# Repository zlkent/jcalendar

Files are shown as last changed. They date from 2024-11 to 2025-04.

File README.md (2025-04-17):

# J-Calendar
墨水屏日历，采用三色4.2寸墨水屏，展示基本月历信息，支持农历、公共假期、倒计日、天气（实时天气、每日天气）展示。<br>
项目以低难度、低成本的方式，方便爱好者实现属于自己的低功耗月历。<br>
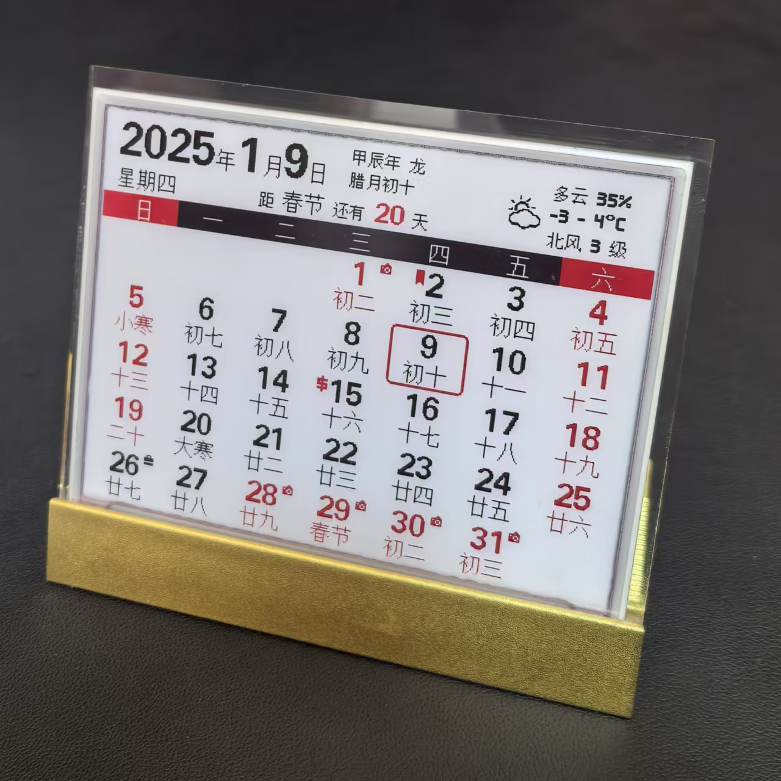
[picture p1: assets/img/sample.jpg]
<br>
Bilibili连接：https://www.bilibili.com/video/BV1wHDhYoE3G/<br>
注：固件仅供个人下载免费使用，禁止商用。

## Prepare & Meterial
1. esp32开发板(建议lolin32 lite,其他esp32开发板亦可)<br>
2. 4.2寸三色墨水屏(400*300)。
3. 通用墨水屏驱动板。
4. 锂电池,需要做ph2.0接头。(建议603048, 900mah)
5. 金属底座亚克力台卡,95*80mm。
6. 轻触开关,(12\*12\*7.3,带键帽)
7. 工具:电烙铁、电线若干。

## Manufacture Guide:
1. 开发板接线<br>
    * 墨水屏驱动板
        * Busy->4
        * RST->16
        * DC->17
        * CS->5
        * SCK->18
        * SDA->23
        * GND->GND
        * VCC->3V
    * 其他
        * 按钮->(PIN_14, GND)
        * LED->22(板载)
2. 三色墨水屏排线插入时注意针脚方向,屏幕排线和驱动板排线1号针脚均是悬空,注意对齐。
3. 电池接口需要是ph2.0,且注意正负极(开发板上有标注),如果电池的正负极反了,可以用镊子调整电池插头。
4. 烧录固件<br>
    使用ESP32的烧录工具flash_download_tool烧录固件. [Flash Download Tools](https://www.espressif.com/en/support/download/other-tools?keys=flash+download+tools)
    1. 选择烧录的文件和烧录地址（bootloader.bin与partitions.bin烧录过一次后，就不需要重复烧录了）
    2. 选择Flash的配置信息
    3. 选择连接的串口以及波特率（波特率可以根据实际情况调整）
    4. 擦除Flash。
    5. 开始烧录。<br>
    <span style="color:red">注：文件前面一定要打勾，否则不会刷进flash的！！！</span><br>
    （参考下图）<br>
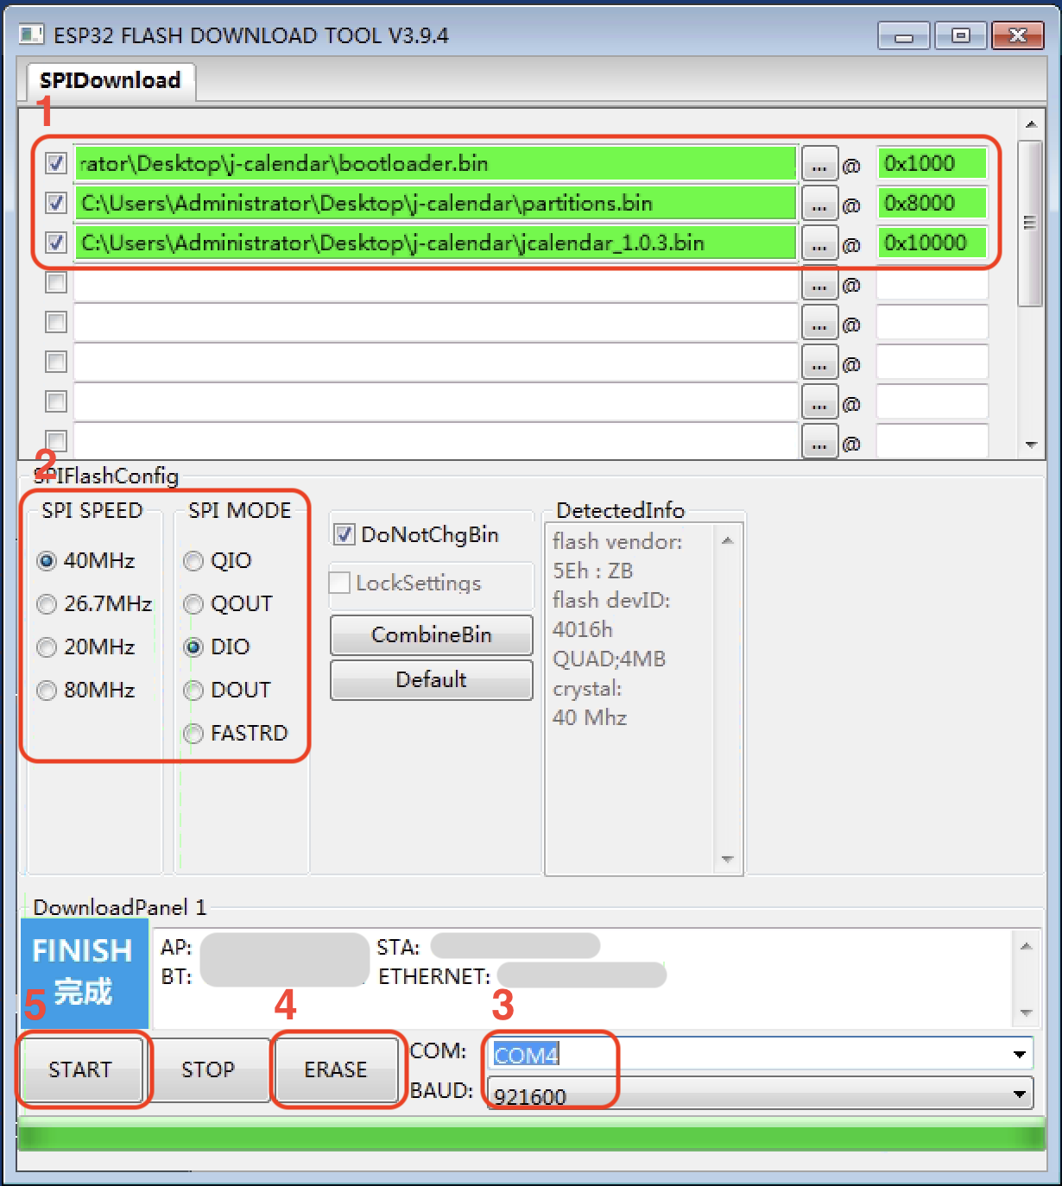
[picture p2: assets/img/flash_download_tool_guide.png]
    
5. 安装盒，3D打印，用PLA或ABS均可。[E-ink box2 v22.3mf](./assets/file/E-ink%20box2%20v22.3mf)

## Button Operation Guide:
1. **单点**  
    如果处在休眠中,唤醒系统,并强制刷新月历。
    如果处在运行中,强制刷新日历。
    如果处在配置中,不做任何处理。
2. **双击**  
    系统正常运行中,双击进入系统配置。(并强制停止WIFI相关操作,如获取天气。)
    系统配置状态中,双击重启系统。
3. **长按**  
    系统运行中,长按清除配置信息(WIFI密钥除外)和缓存,并重启。

## LED Indicator: 
(板载LED,PIN-22)
1. 快闪: LED每秒闪约两次，系统启动中(正在连接WIFI)
2. 常亮: WIFI连接完成。
3. 慢闪: LED每两秒闪一次，WIFI连接失败（10秒钟后休眠）。
4. 三短闪一长灭: 系统配置中。（3分钟后超时休眠）
5. 熄灭: 系统休眠。

## Web Config Guide:
通过在开机状态下(LED常亮)双击,即可进入配置状态,这时系统会生成一个名为J-Calendar的ap,默认密码为:password。(默认超时时间为180秒)
连接上ap后会直接弹出配置页面。(或者直接通过浏览器输入地址 http://192.168.4.1进入)。
配置页面:
1. Config Wifi. Wifi配置  
    进入配置wifi页面,选择搜索到的ap,并输入密码,并保存。
2. Setup. 系统配置  
    * 周首日:
        * 0: 周日(默认); 1: 周一;
    * 和风天气:
        * 输入和风天气的API Key和城市id(城市对应的id请在和风天气的官网查找。)系统会每2小时刷新当前天气,如果Key置空,天气将不会被刷新。<br>
        * 天气类型：0:每日天气（默认，每天凌晨刷新一次）; 1: 实时天气(每两个小时刷新一次天气)<br>
        * 位置：城市id或者经纬度 例1: 101010100 例2: 116.41,39.92<br>
        [城市id列表](./assets/file/China-City-List-latest.csv) <br>
    * 倒数日:<br>输入倒数日名称和日期,名称不能超过4个中文字符,时间以yyyyMMdd的格式填入。配置正确的话,日历每天会显示倒数“距****还有**天”。如果倒数日名称为空,系统将不显示倒数日信息。
    * 日期Tag:<br>
        1. 输入格式，yyyyMMddx，yyyy为年，每年显示设为0000，MM为月份，每月显示设为00，dd为日期，x为tag的图标（a:书签；b：金钱；c：笑脸；d：警告）。例如：00000015b，每年每月15日旁边显示$符号；00000312a，每年3月12日，显示书签符号。
        2. 最多可以设置三个tag，中间以分号隔开。例如：00000015b;00000312a
    * 保存配置后，系统自动重启。
3. Update. OTA升级  
    此项需要在浏览器内完成,通过ip地址访问配置页面,然后进入Update,选择固件文件后上传,等待。刷新完成后,页面会有成功提示。
4. Restart. 重启  
    在所有配置完后,需要重启生效。(也可以在配置状态下,双击按钮重启)
5. Info. 系统信息
    可以监控系统的硬件情况,也可以在里面清除配置的Wifi密钥。
6. Exit. 退出  
    退出配置状态。

## Q & A
1. Q: 刷完机后，如何配置？启动流程是如何的？<br>
A: 需要在系统运行状态下（状态灯常亮或慢闪时）双击按键，即可进入配置状态。LED灯变成三短闪一长灭时说明进入配置状态了。
2. Q: 刷完机后，没有反应该如何处理？<br>
A: 观察22针脚的LED是否点亮，有闪烁说明固件已经刷入，如果没有闪烁可以尝试点击重置按钮重启，或者拔掉电源线和usb线，重插来重启。此外，还可使用串口工具通过usb的com口获取启动日志来进一步确认故障原因。
3. Q: 可以支持哪种屏？<br>
A: 仅4.2寸三色屏(目前仅支持黑白红,将来支持黑白黄)。
4. Q: 我使用的屏应该烧录哪个固件？<br>
A: 从经验上预估，SES的拆机屏选z21，比较新一些的选z98，如果是非常老的屏，选z15。实在不行的话，三个固件都刷一遍试试。<br>
明确的丝印对应如下：<br>
    |丝印|固件|
    |-----|-----|
    |E042A43-A0|z98|
    |P420010|z98|
    |A13600**|z21|
5. Q: 使用flash download tool刷新固件时，报错，连接串口失败。<br>
A: 1. 检查USB线连接是否正常。 <br>2. app的串口下拉框里是否检测到COM口。 <br>3. 把其他串口工具关闭，防止占用COM口。
6. Q: 刷新固件的过程中提示报错。<br>
A: 1. 换根质量较好的或短一些的USB线，或换个USB口插入。 <br>2. 可以将刷新的波特率降低一点，如选择速率低一点的115200。
7. Q: 刷新固件后，需要重新配置吗？
A: 仅刷新app固件后，配置是保留的，所以，无需重新配置。如果刷新了分区表partition.bin，会将esp的nvs区刷新，这时候需要重新配置。
8. Q: 填入和风天气的API Key和位置ID后，没有成功获取天气信息。
A: 2025年3月1日后注册的和风天气账户有API Host限制，请下载1.0.25以后版本，在配置时配置API Host信息。

## Releases
### 1.0.25 (未测试)
* Fix: 和风天气api变更，需要输入API Host（在配置页面增加配置项）
### 1.0.24
* Refine: 配置页面location约束改为64长度，允许输入经纬度设置天气位置（e.g. 116.41,39.92）
### 1.0.23
* Refine: 修改和风天气请求url。
* Fix: bug(获取holiday返回码)。
### 1.0.22
* 项目开源：此项目使用GNU General Public License v3.0许可证授权。详情请参阅LICENSE文件。
* Refine：农历计算功能移出。（农历功能作为独立库，以MIT协议开源）
### 1.0.21
* Fix: bug (wrong background color of calender header).
### 1.0.20
* Fix: bugs.
### 1.0.19
* New: 假日信息通过网络API获取。
* Refine: 由于esp32内置时钟的误差，会有可能唤醒的时间不准确，同时，由于处于午夜0点左右，导致提前刷新或在刷新期间切换日期，导致日期显示不准确。处理方式：计时器唤醒的情况下，23:50以后不刷新直接休眠，等待至0点以后唤醒刷新。
### 1.0.18
* Fix: 修正Wifi连接失败后，同步时间导致系统时间错误。
### 1.0.17
* Refine: 如果wifi连接失败，等待10s再休眠，并增加LED慢闪作为指示。（在这时间段内供用户进行双击打开配置状态）
* Fix: 修正倒数日名称显示不足的问题。
### 1.0.16
* New Feature: UI调整，新增今日农历日期的展现。
### 1.0.15
* Fix: 编译异常。
### 1.0.14
* Fix: bug(假日颜色不正确), 增加显示假日和调休icon(日历右上角)。
### 1.0.13
* Fix: bugs.
### 1.0.12
* 新功能：增加设置每周首日，默认首日为周日。
### 1.0.11
* 优化：补充部分公历&农历节日
### 1.0.10
* 新功能：增加日期Tag（通过配置页面进行配置）
### 1.0.9
* 优化：
    1. 统一每日天气与实时天气的布局。
    2. 增加时间容错性，当同步网络时间失败的时候，使用天气api的更新时间。
* 新功能：增加节日显示（元旦、劳动节、国庆节）
### 1.0.8
* 优化显示：加粗当前日期框；不再使用局刷，全部改为全屏刷新（提高显示的清晰度，兼容不支持局部刷新的三色屏）。
* 预置2025年公休假信息。
### 1.0.7
* 增加24节气显示。修复部分bug。
### 1.0.6
* 增加天气模式--*每日天气*（默认配置），每天刷新一次。（增加月历待机时长。部分不支持局刷的屏可以选择这个模式。）
### 1.0.5 
* 增加强制刷新处理(单击按钮)。
* 修复日历功能、修复日历字典数据
* 修复部分bug。
### 1.0.4<br>
* 增加倒计日功能
* 修复部分bug。
### 1.0.3
* 基本功能
* 功耗优化等

## License
此项目使用GNU General Public License v3.0许可证授权。详情请参阅LICENSE文件。

### ★★★固件还不错，支持一下★★★
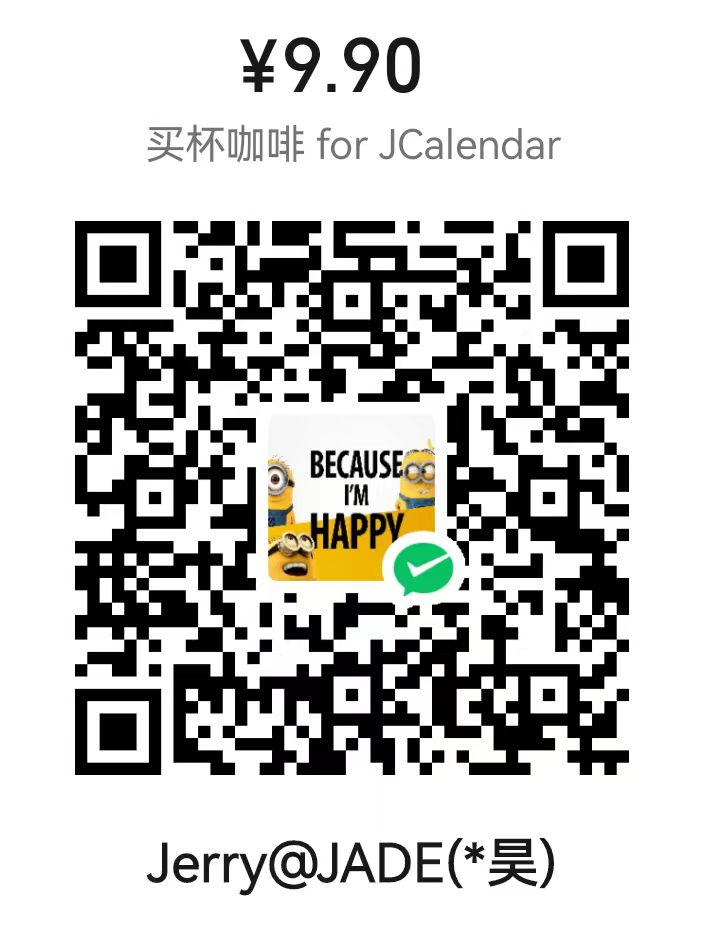
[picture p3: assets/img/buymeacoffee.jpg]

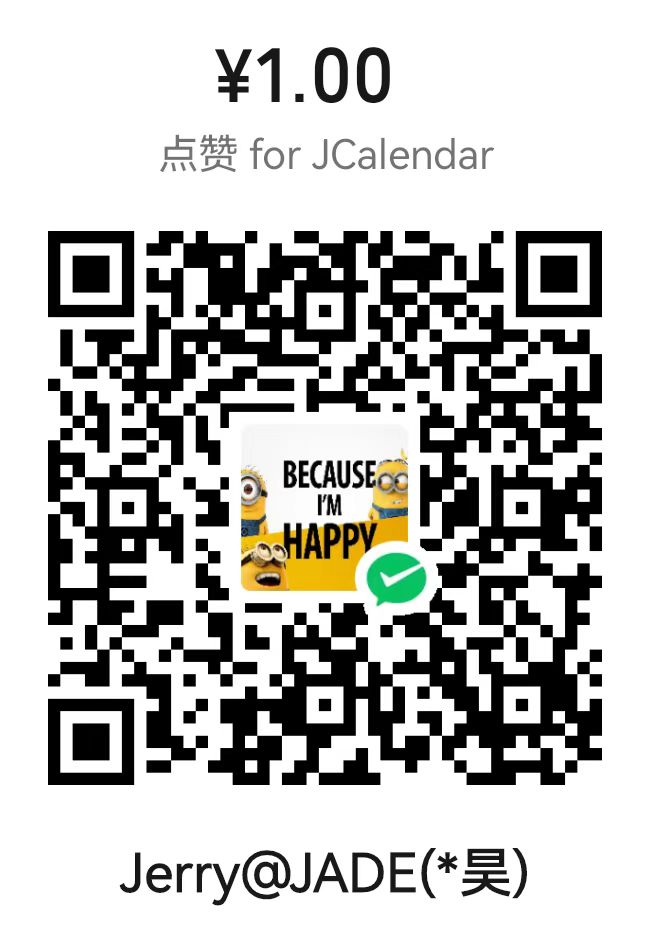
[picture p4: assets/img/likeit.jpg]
<br>

## Reference:
1. \<WEMOS LOLIN32簡介\> https://swf.com.tw/?p=1331&cpage=1
2. \<GxEPD2\> https://github.com/ZinggJM/GxEPD2
3. \<U8g2_for_Adafruit_GFX\> https://github.com/olikraus/U8g2_for_Adafruit_GFX
4. \<和风天气\> https://dev.qweather.com/docs/api/weather/weather-now/
<br>
 Copyright © 2023-2025. All Rights Reserved.

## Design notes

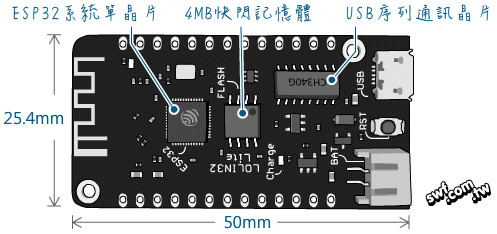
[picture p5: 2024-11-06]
assets/img/LOLIN32_Lite.png

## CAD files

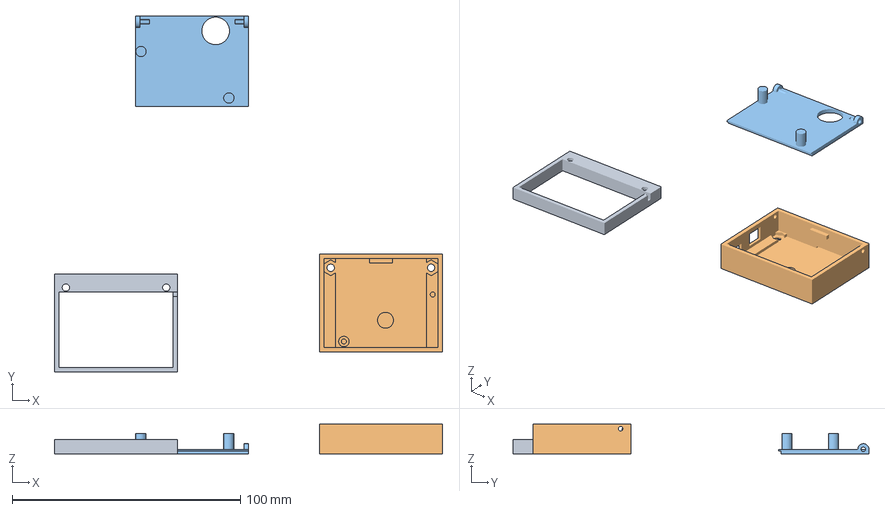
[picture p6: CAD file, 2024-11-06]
assets/file/E-ink box2 v22.3mf
170.1 x 156.0 x 13.0 mm
零部件3
零部件1
实体1.stl

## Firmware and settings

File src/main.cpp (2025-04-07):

#include <Arduino.h>
#include <ArduinoJson.h>

#include <WiFiManager.h>

#include "OneButton.h"

#include "led.h"
#include "_sntp.h"
#include "weather.h"
#include "screen_ink.h"
#include "_preference.h"

#include "version.h"

#define PIN_BUTTON GPIO_NUM_14 // 注意：由于此按键负责唤醒，因此需要选择支持RTC唤醒的PIN脚。
OneButton button(PIN_BUTTON, true);

void IRAM_ATTR checkTicks() {
    button.tick();
}

WiFiManager wm;
WiFiManagerParameter para_qweather_host("qweather_host", "和风天气Host", "", 64); //     和风天气key
WiFiManagerParameter para_qweather_key("qweather_key", "和风天气API Key", "", 32); //     和风天气key
// const char* test_html = "<br/><label for='test'>天气模式</label><br/><input type='radio' name='test' value='0' checked> 每日天气test </input><input type='radio' name='test' value='1'> 实时天气test</input>";
// WiFiManagerParameter para_test(test_html);
WiFiManagerParameter para_qweather_type("qweather_type", "天气类型（0:每日天气，1:实时天气）", "0", 2, "pattern='\\[0-1]{1}'"); //     城市code
WiFiManagerParameter para_qweather_location("qweather_loc", "位置ID", "", 64); //     城市code
WiFiManagerParameter para_cd_day_label("cd_day_label", "倒数日（4字以内）", "", 10); //     倒数日
WiFiManagerParameter para_cd_day_date("cd_day_date", "日期（yyyyMMdd）", "", 8, "pattern='\\d{8}'"); //     城市code
WiFiManagerParameter para_tag_days("tag_days", "日期Tag（yyyyMMddx，详见README）", "", 30); //     日期Tag
WiFiManagerParameter para_si_week_1st("si_week_1st", "每周起始（0:周日，1:周一）", "0", 2, "pattern='\\[0-1]{1}'"); //     每周第一天

void print_wakeup_reason() {
    esp_sleep_wakeup_cause_t wakeup_reason = esp_sleep_get_wakeup_cause();
    switch (wakeup_reason) {
    case ESP_SLEEP_WAKEUP_EXT0:
        Serial.println("Wakeup caused by external signal using RTC_IO");
        break;
    case ESP_SLEEP_WAKEUP_EXT1:
        Serial.println("Wakeup caused by external signal using RTC_CNTL");
        break;
    case ESP_SLEEP_WAKEUP_TIMER:
        Serial.println("Wakeup caused by timer");
        break;
    case ESP_SLEEP_WAKEUP_TOUCHPAD:
        Serial.println("Wakeup caused by touchpad");
        break;
    case ESP_SLEEP_WAKEUP_ULP:
        Serial.println("Wakeup caused by ULP program");
        break;
    default:
        Serial.printf("Wakeup was not caused by deep sleep.\n");
    }
}

void buttonClick(void* oneButton);
void buttonDoubleClick(void* oneButton);
void buttonLongPressStop(void* oneButton);
void go_sleep();

unsigned long _idle_millis;
unsigned long TIME_TO_SLEEP = 180 * 1000;

bool _wifi_flag = false;
unsigned long _wifi_failed_millis;
void setup() {
    delay(10);
    Serial.begin(115200);
    Serial.println(".");
    print_wakeup_reason();
    Serial.println("\r\n\r\n\r\n");
    delay(10);

    button.setClickMs(300);
    button.setPressMs(3000); // 设置长按的时长
    button.attachClick(buttonClick, &button);
    button.attachDoubleClick(buttonDoubleClick, &button);
    // button.attachMultiClick()
    button.attachLongPressStop(buttonLongPressStop, &button);
    attachInterrupt(digitalPinToInterrupt(PIN_BUTTON), checkTicks, CHANGE);

    Serial.printf("***********************\r\n");
    Serial.printf("      J-Calendar\r\n");
    Serial.printf("    version: %s\r\n", J_VERSION);
    Serial.printf("***********************\r\n\r\n");
    Serial.printf("Copyright © 2022-2025 JADE Software Co., Ltd. All Rights Reserved.\r\n\r\n");

    led_init();
    led_fast();
    Serial.println("Wm begin...");
    wm.setHostname("J-Calendar");
    wm.setEnableConfigPortal(false);
    wm.setConnectTimeout(10);
    if (wm.autoConnect()) {
        Serial.println("Connect OK.");
        led_on();
        _wifi_flag = true;
    } else {
        Serial.println("Connect failed.");
        _wifi_flag = false;
        _wifi_failed_millis = millis();
        led_slow();
        _sntp_exec(2);
        weather_exec(2);
        WiFi.mode(WIFI_OFF); // 提前关闭WIFI，省电
        Serial.println("Wifi closed.");
    }
}

/**
 * 处理各个任务
 * 1. sntp同步
 *      前置条件：Wifi已连接
 * 2. 刷新日历
 *      前置条件：sntp同步完成（无论成功或失败）
 * 3. 刷新天气信息
 *      前置条件：wifi已连接
 * 4. 系统配置
 *      前置条件：无
 * 5. 休眠
 *      前置条件：所有任务都完成或失败，
 */
void loop() {
    button.tick(); // 单击，刷新页面；双击，打开配置；长按，重启
    wm.process();
    // 前置任务：wifi已连接
    // sntp同步
    if (_sntp_status() == -1) {
        _sntp_exec();
    }
    // 如果是定时器唤醒，并且接近午夜（23:50之后），则直接休眠
    if (_sntp_status() == SYNC_STATUS_TOO_LATE) {
        go_sleep();
    }
    // 前置任务：wifi已连接
    // 获取Weather信息
    if (weather_status() == -1) {
        weather_exec();
    }

    // 刷新日历
    // 前置任务：sntp、weather
    // 执行条件：屏幕状态为待处理
    if (_sntp_status() > 0 && weather_status() > 0 && si_screen_status() == -1) {
        // 数据获取完毕后，关闭Wifi，省电
        if (!wm.getConfigPortalActive()) {
            WiFi.mode(WIFI_OFF);
        }
        Serial.println("Wifi closed after data fetch.");

        si_screen();
    }

    // 休眠
    // 前置条件：屏幕刷新完成（或成功）

    // 未在配置状态，且屏幕刷新完成，进入休眠
    if (!wm.getConfigPortalActive() && si_screen_status() > 0) {
        if(_wifi_flag) {
            go_sleep();
        }
        if(!_wifi_flag && millis() - _wifi_failed_millis > 10 * 1000) { // 如果wifi连接不成功，等待10秒休眠
            go_sleep();
        }
    }
    // 配置状态下，
    if (wm.getConfigPortalActive() && millis() - _idle_millis > TIME_TO_SLEEP) {
        go_sleep();
    }

    delay(10);
}


// 刷新页面
void buttonClick(void* oneButton) {
    Serial.println("Button click.");
    if (wm.getConfigPortalActive()) {
        Serial.println("In config status.");
    } else {
        Serial.println("Refresh screen manually.");
        si_screen();
    }
}

void saveParamsCallback() {
    Preferences pref;
    pref.begin(PREF_NAMESPACE);
    pref.putString(PREF_QWEATHER_HOST, para_qweather_host.getValue());
    pref.putString(PREF_QWEATHER_KEY, para_qweather_key.getValue());
    pref.putString(PREF_QWEATHER_TYPE, strcmp(para_qweather_type.getValue(), "1") == 0 ? "1" : "0");
    pref.putString(PREF_QWEATHER_LOC, para_qweather_location.getValue());
    pref.putString(PREF_CD_DAY_LABLE, para_cd_day_label.getValue());
    pref.putString(PREF_CD_DAY_DATE, para_cd_day_date.getValue());
    pref.putString(PREF_TAG_DAYS, para_tag_days.getValue());
    pref.putString(PREF_SI_WEEK_1ST, strcmp(para_si_week_1st.getValue(), "1") == 0 ? "1" : "0");
    pref.end();

    Serial.println("Params saved.");

    _idle_millis = millis(); // 刷新无操作时间点

    ESP.restart();
}

void preSaveParamsCallback() {
}

// 双击打开配置页面
void buttonDoubleClick(void* oneButton) {
    Serial.println("Button double click.");
    if (wm.getConfigPortalActive()) {
        ESP.restart();
        return;
    }

    if (weather_status == 0) {
        weather_stop();
    }

    // 设置配置页面
    // 根据配置信息设置默认值
    Preferences pref;
    pref.begin(PREF_NAMESPACE);
    String qHost = pref.getString(PREF_QWEATHER_HOST);
    String qToken = pref.getString(PREF_QWEATHER_KEY);
    String qType = pref.getString(PREF_QWEATHER_TYPE, "0");
    String qLoc = pref.getString(PREF_QWEATHER_LOC);
    String cddLabel = pref.getString(PREF_CD_DAY_LABLE);
    String cddDate = pref.getString(PREF_CD_DAY_DATE);
    String tagDays = pref.getString(PREF_TAG_DAYS);
    String week1st = pref.getString(PREF_SI_WEEK_1ST, "0");
    pref.end();

    para_qweather_host.setValue(qHost.c_str(), 64);
    para_qweather_key.setValue(qToken.c_str(), 32);
    para_qweather_location.setValue(qLoc.c_str(), 64);
    para_qweather_type.setValue(qType.c_str(), 1);
    para_cd_day_label.setValue(cddLabel.c_str(), 16);
    para_cd_day_date.setValue(cddDate.c_str(), 8);
    para_tag_days.setValue(tagDays.c_str(), 30);
    para_si_week_1st.setValue(week1st.c_str(), 1);

    wm.setTitle("J-Calendar");
    wm.addParameter(&para_si_week_1st);
    wm.addParameter(&para_qweather_host);
    wm.addParameter(&para_qweather_key);
    wm.addParameter(&para_qweather_type);
    wm.addParameter(&para_qweather_location);
    wm.addParameter(&para_cd_day_label);
    wm.addParameter(&para_cd_day_date);
    wm.addParameter(&para_tag_days);
    // std::vector<const char *> menu = {"wifi","wifinoscan","info","param","custom","close","sep","erase","update","restart","exit"};
    std::vector<const char*> menu = { "wifi","param","update","sep","info","restart","exit" };
    wm.setMenu(menu); // custom menu, pass vector
    wm.setConfigPortalBlocking(false);
    wm.setBreakAfterConfig(true);
    wm.setPreSaveParamsCallback(preSaveParamsCallback);
    wm.setSaveParamsCallback(saveParamsCallback);
    wm.setSaveConnect(false); // 保存完wifi信息后是否自动连接，设置为否，以便于用户继续配置param。
    wm.startConfigPortal("J-Calendar", "password");

    led_config(); // LED 进入三快闪状态

    // 控制配置超时180秒后休眠
    _idle_millis = millis();
}


// 重置系统，并重启
void buttonLongPressStop(void* oneButton) {
    Serial.println("Button long press.");

    // 删除Preferences，namespace下所有健值对。
    Preferences pref;
    pref.begin(PREF_NAMESPACE);
    pref.clear();
    pref.end();

    ESP.restart();
}

#define uS_TO_S_FACTOR 1000000
#define TIMEOUT_TO_SLEEP  10 // seconds
time_t blankTime = 0;
void go_sleep() {
    // 设置唤醒时间为下个偶数整点。
    time_t now = time(NULL);
    struct tm tmNow = { 0 };
    // Serial.printf("Now: %ld -- %s\n", now, ctime(&now));
    localtime_r(&now, &tmNow); // 时间戳转化为本地时间结构

    uint64_t p;
    // 根据配置情况来刷新，如果未配置qweather信息，则24小时刷新，否则每2小时刷新
    Preferences pref;
    pref.begin(PREF_NAMESPACE);
    String _qweather_key = pref.getString(PREF_QWEATHER_KEY, "");
    pref.end();
    if (_qweather_key.length() == 0 || weather_type() == 0) { // 没有配置天气或者使用按日天气，则第二天刷新。
        Serial.println("Sleep to next day.");
        now += 3600 * 24;
        localtime_r(&now, &tmNow); // 将新时间转成tm
        // Serial.printf("Set1: %ld -- %s\n", now, ctime(&now));

        struct tm tmNew = { 0 };
        tmNew.tm_year = tmNow.tm_year;
        tmNew.tm_mon = tmNow.tm_mon;        // 月份从0开始
        tmNew.tm_mday = tmNow.tm_mday;           // 日期
        tmNew.tm_hour = 0;           // 小时
        tmNew.tm_min = 0;            // 分钟
        tmNew.tm_sec = 10;            // 秒, 防止离线时出现时间误差，所以，延后10s
        time_t set = mktime(&tmNew);

        p = (uint64_t)(set - time(NULL));
        Serial.printf("Sleep time: %ld seconds\n", p);
    } else {
        if (tmNow.tm_hour % 2 == 0) { // 将时间推后两个小时，偶整点刷新。
            now += 7200;
        } else {
            now += 3600;
        }
        localtime_r(&now, &tmNow); // 将新时间转成tm
        // Serial.printf("Set1: %ld -- %s\n", now, ctime(&now));

        struct tm tmNew = { 0 };
        tmNew.tm_year = tmNow.tm_year;
        tmNew.tm_mon = tmNow.tm_mon;        // 月份从0开始
        tmNew.tm_mday = tmNow.tm_mday;           // 日期
        tmNew.tm_hour = tmNow.tm_hour;           // 小时
        tmNew.tm_min = 0;            // 分钟
        tmNew.tm_sec = 10;            // 秒, 防止离线时出现时间误差，所以，延后10s
        time_t set = mktime(&tmNew);

        p = (uint64_t)(set - time(NULL));
        Serial.printf("Sleep time: %ld seconds\n", p);
    }

    esp_sleep_enable_timer_wakeup(p * (uint64_t)uS_TO_S_FACTOR);
    esp_sleep_enable_ext0_wakeup(PIN_BUTTON, 0);

    // 省电考虑，关闭RTC外设和存储器
    // esp_sleep_pd_config(ESP_PD_DOMAIN_RTC_PERIPH, ESP_PD_OPTION_OFF); // RTC IO, sensors and ULP, 注意：由于需要按键唤醒，所以不能关闭，否则会导致RTC_IO唤醒失败
    esp_sleep_pd_config(ESP_PD_DOMAIN_RTC_SLOW_MEM, ESP_PD_OPTION_OFF); // 
    esp_sleep_pd_config(ESP_PD_DOMAIN_RTC_FAST_MEM, ESP_PD_OPTION_OFF);

    // 省电考虑，重置gpio，平均每针脚能省8ua。
    gpio_reset_pin(PIN_LED); // 减小deep-sleep电流
    gpio_reset_pin(GPIO_NUM_5); // 减小deep-sleep电流
    gpio_reset_pin(GPIO_NUM_17); // 减小deep-sleep电流
    gpio_reset_pin(GPIO_NUM_16); // 减小deep-sleep电流
    gpio_reset_pin(GPIO_NUM_4); // 减小deep-sleep电流

    delay(10);
    Serial.println("Deep sleep...");
    Serial.flush();
    esp_deep_sleep_start();
}

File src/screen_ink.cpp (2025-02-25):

#include "screen_ink.h"

#include <weather.h>
#include <API.hpp>
#include "holiday.h"
#include "nongli.h"

#include <_preference.h>

#include <U8g2_for_Adafruit_GFX.h>
#include <GxEPD2_3C.h>
#include "GxEPD2_display_selection_new_style.h"

#include "font.h"
#define ROTATION 0

GxEPD2_DISPLAY_CLASS<GxEPD2_DRIVER_CLASS, GxEPD2_DRIVER_CLASS::HEIGHT> display(GxEPD2_DRIVER_CLASS(/*CS=D8*/ 5, /*DC=D3*/ 17, /*RST=D4*/ 16, /*BUSY=D2*/ 4));
U8G2_FOR_ADAFRUIT_GFX u8g2Fonts;


#define FONT_TEXT u8g2_font_wqy16_t_gb2312 // 224825bytes，最大字库（天气描述中“霾”，只有此字库中有）
#define FONT_SUB u8g2_font_wqy12_t_gb2312 // 次要字体，u8g2最小字体
const String week_str[] = { "日", "一", "二", "三", "四", "五", "六" };
// const String tg_str[] = { "甲", "乙", "丙", "丁", "戊", "己", "庚", "辛", "壬", "癸" };            // 天干
// const String dz_str[] = { "子", "丑", "寅", "卯", "辰", "巳", "午", "未", "申", "酉", "戌", "亥" }; // 地支
// const String sx_str[] = { "鼠", "牛", "虎", "兔", "龙", "蛇", "马", "羊", "猴", "鸡", "狗", "猪" }; // 生肖
const String nl10_str[] = { "初", "十", "廿", "卅" }; // 农历十位
const String nl_str[] = { "十", "一", "二", "三", "四", "五", "六", "七", "八", "九", "十" }; // 农历个位
const String nl_mon_str[] = { "", "正", "二", "三", "四", "五", "六", "七", "八", "九", "十", "冬", "腊" }; // 农历首位

int _screen_status = -1;
int _calendar_status = -1;
String _cd_day_label;
String _cd_day_date;
String _tag_days_str;
int _week_1st;
int lunarDates[31];
int jqAccDate[24]; // 节气积累日

const int jrLength = 11;
const int jrDate[] = { 101, 214, 308, 312, 501, 504, 601, 701, 801, 910, 1001, 1224, 1225 };
const String jrText[] = { "元旦", "情人节", "妇女节", "植树节", "劳动节", "青年节", "儿童节", "建党节", "建军节", "教师节", "国庆节", "平安夜", "圣诞节" };

struct tm tmInfo = { 0 }; // 日历显示用的时间

struct
{
    int16_t topX;
    int16_t topY;
    int16_t topW;
    int16_t topH;

    int16_t tX;
    int16_t tY;
    int16_t tW;
    int16_t tH;

    int16_t yearX;
    int16_t yearY;
    int16_t weekX;
    int16_t weekY;

    int16_t lunarYearX;
    int16_t lunarYearY;
    int16_t lunarDayX;
    int16_t lunarDayY;
    int16_t cdDayX;
    int16_t cdDayY;

    int16_t weatherX;
    int16_t weatherY;
    int16_t weatherW;
    int16_t weatherH;

    int16_t headerX;
    int16_t headerY;
    int16_t headerW;
    int16_t headerH;

    int16_t daysX;
    int16_t daysY;
    int16_t daysW;
    int16_t daysH;
    int16_t dayW;
    int16_t dayH;
} static calLayout;

TaskHandle_t SCREEN_HANDLER;

void init_cal_layout_size() {
    calLayout.topX = 0;
    calLayout.topY = 0;
    calLayout.topW = 180;
    calLayout.topH = 60;

    calLayout.yearX = 10;
    calLayout.yearY = calLayout.topH - 28;
    calLayout.weekX = 10;
    calLayout.weekY = calLayout.topH - 5;

    calLayout.lunarYearX = calLayout.topX + calLayout.topW;
    calLayout.lunarYearY = calLayout.yearY / 2;
    calLayout.lunarDayX = calLayout.topX + calLayout.topW;
    calLayout.lunarDayY = calLayout.yearY;

    calLayout.cdDayX = 0;
    calLayout.cdDayY = calLayout.topH - 5;

    calLayout.tX = calLayout.topX + calLayout.topW;
    calLayout.tY = calLayout.topY;
    calLayout.tW = 60;
    calLayout.tH = calLayout.topH / 2;

    calLayout.weatherX = 300;
    calLayout.weatherY = calLayout.topY;
    calLayout.weatherW = display.width() - calLayout.weatherX;
    calLayout.weatherH = calLayout.topH;

    calLayout.headerX = calLayout.topX;
    calLayout.headerY = calLayout.topY + calLayout.topH;
    calLayout.headerW = display.width();
    calLayout.headerH = 20;

    calLayout.daysX = calLayout.topX;
    calLayout.daysY = calLayout.headerY + calLayout.headerH;
    calLayout.daysW = calLayout.headerW;
    calLayout.daysH = display.height() - calLayout.daysX;
    calLayout.dayW = 56;
    calLayout.dayH = 44;
}

void draw_cal_layout() {
    uint16_t color;

    u8g2Fonts.setFont(FONT_TEXT);
    u8g2Fonts.setFontMode(1);
    u8g2Fonts.setFontDirection(0);
    u8g2Fonts.setForegroundColor(GxEPD_WHITE);
    int16_t daysMagin = 4;

    for (int i = 0; i < 7; i++) {
        if((i + _week_1st) % 7 == 0 || (i + _week_1st) % 7 == 6) {
            color = GxEPD_RED;
        } else {
            color = GxEPD_BLACK;
        }
        // header background
        if(i == 0) {
            display.fillRect(0, calLayout.headerY, (display.width() - 7 * calLayout.dayW)/2, calLayout.headerH, color);
        } else if(i == 6) {
            display.fillRect((display.width() + 7 * calLayout.dayW)/2, calLayout.headerY, (display.width() - 7 * calLayout.dayW)/2, calLayout.headerH, color);
        }
        display.fillRect((display.width() - 7 * calLayout.dayW)/2 + i * calLayout.dayW, calLayout.headerY, calLayout.dayW, calLayout.headerH, color);
        
        // header text
        u8g2Fonts.drawUTF8(calLayout.headerX + daysMagin + (calLayout.dayW - u8g2Fonts.getUTF8Width(week_str[i].c_str())) / 2 + i * calLayout.dayW, calLayout.headerY + calLayout.headerH - 3, week_str[(i + _week_1st) % 7].c_str());
    }
}

uint16_t todayColor = GxEPD_BLACK;
String todayLunarYear;
String todayLunarDay;
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

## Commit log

2024-11-10 update sample img
2025-03-08 Update holiday.cpp
    ArduinoJson 7.3 开始，MemberProxy 和 ElementProxy 变更为non-copyable，所以doc["code"]必须先显式转换到int再做判断。
